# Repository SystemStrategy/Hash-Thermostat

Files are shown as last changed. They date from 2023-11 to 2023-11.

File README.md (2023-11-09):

# Hash-Thermostat

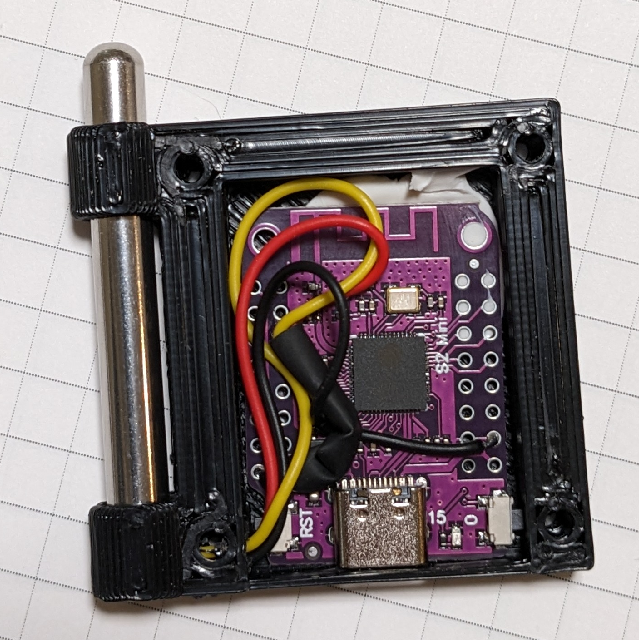
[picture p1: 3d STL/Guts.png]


Braiins OS Hash Thermostat to regulate indoor temperature using the miner API to go between pause and reusme

Tested on an S9 and works, but if you have a newer more supported miner by braiins, there exists the capability to ramp power output up and down. Please put in an issue if you want to dev/test this with me.

Parts used:
ESP32S2 Mini - https://www.wemos.cc/en/latest/s2/s2_mini.html

Temperature Probes Options:
DS18B20
AHT21

Wiring for AHT21
GPIO 21 (SDA)
GPIO 22 (SCL)

Wiring for DS18B20
GPIO 04 with 4.7k pullup resistor to Vcc(3.3v)

Hash Thermostat Quick Start Guide:

Step 1:
	Connect to the WIFI access point “AP_Thermostat” the password is “StackSats!”
	Note: WIFI access point deactivates when rebooted and device connects to network

Step 2:
	Open your web browser and navigate to http://194.168.4.1 or http://thermostat.local/   		
	-Login prompt the username and password are “admin” click “Sign In”

Step 3:
	Enter the desired thermostat behavior using the sliders and click “Apply Settings”

Step 4:
	Navigate to "Configuration" then “Network Parameters”
	
	-Enter Wifi SSID and Password and click “submit” 
	 	If network has connected you should see the Status change to “Connected” otherwise double check the credentials

	-Enter the Miner Static IP and click “submit” 
		If the miner is connected the Status changes to “Hashing” or “Off” depending on the state
	
	-Click the Time Zone dropdown to select your Time Zone and click “submit” 

	When all looks good, click “Main Page”

Step 5: 
	Change the Login Password

Step 6: 
	If you have an MQTT broker you want to send data to click “MQTT Parameters”

Step 7:
	Click the “Reboot” Button
	You should be able to find the device by typing “http://thermostat.local/” in the browser

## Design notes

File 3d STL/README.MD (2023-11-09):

Assembly Notes:

Cut DS18B20 wires to 4 inches from the base of the metal shell
Remove the heat shrink tube
carefully remove the rubber wire jacket

3d print cleanup
use 15/64 inch bit to clear DS18B20 holes
then use 1/4 inch bit to clear the first hole

insert the DS18B20 though the first hole and into the case
then push the temperature sensor in

Solder up the connections for the ESP32S2 Mini

Close using M3*6 screws

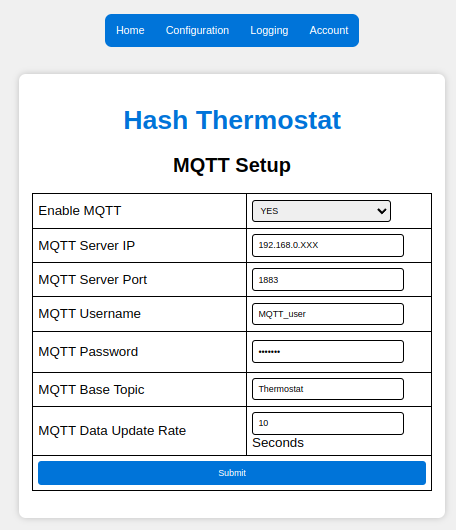
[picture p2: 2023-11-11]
Webpage_Images/MQTT.png

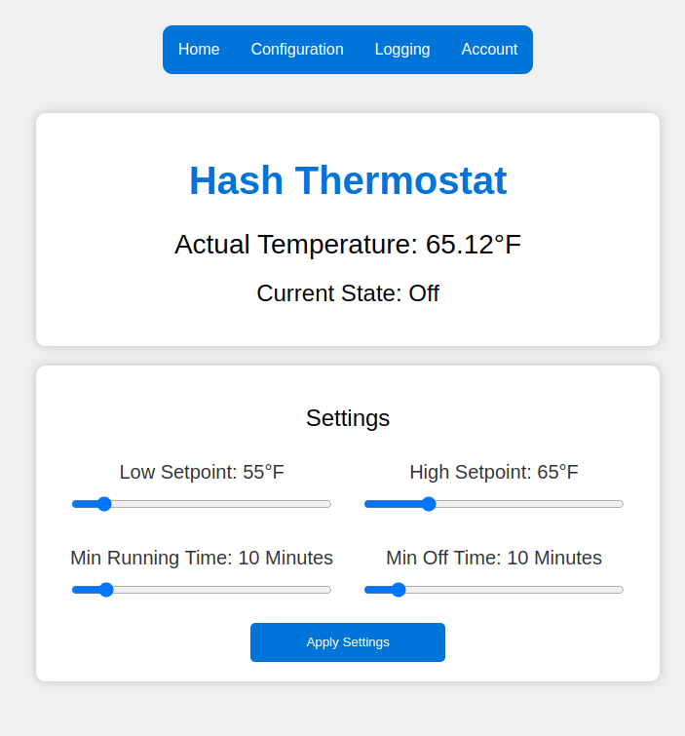
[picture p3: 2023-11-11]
Webpage_Images/Settings.png

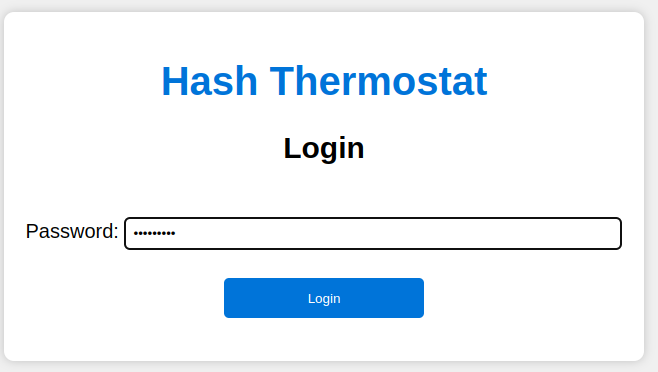
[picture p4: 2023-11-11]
Webpage_Images/Login.png

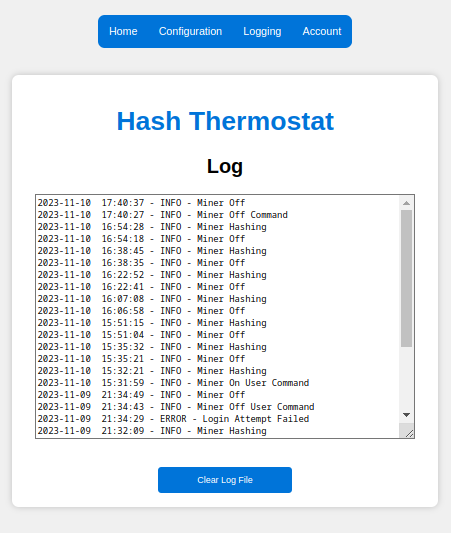
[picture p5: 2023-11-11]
Webpage_Images/Log.png

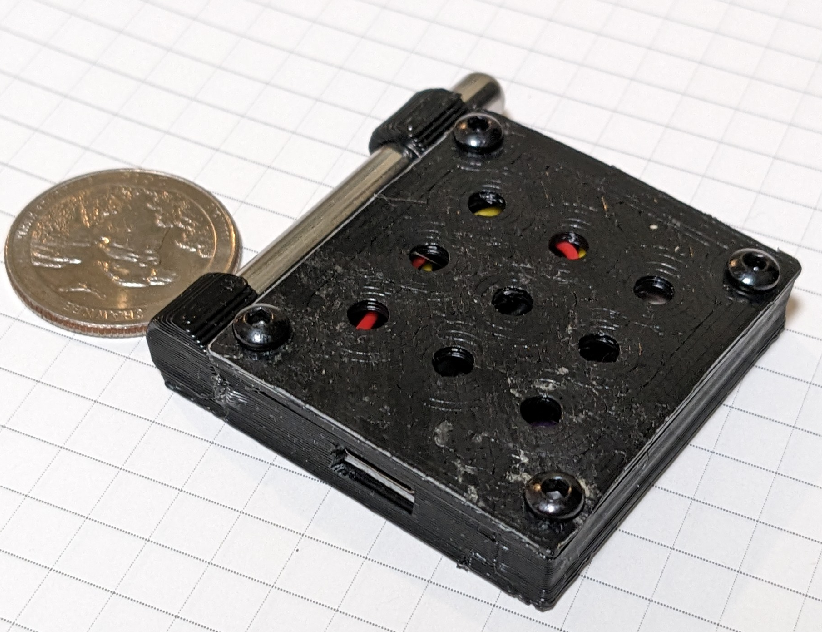
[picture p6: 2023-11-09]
3d STL/Orthogonal.png

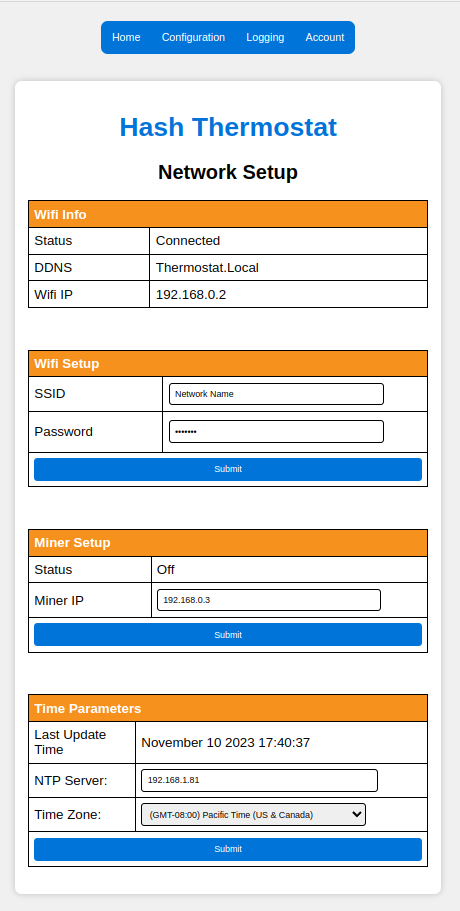
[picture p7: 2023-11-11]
Webpage_Images/Network.png

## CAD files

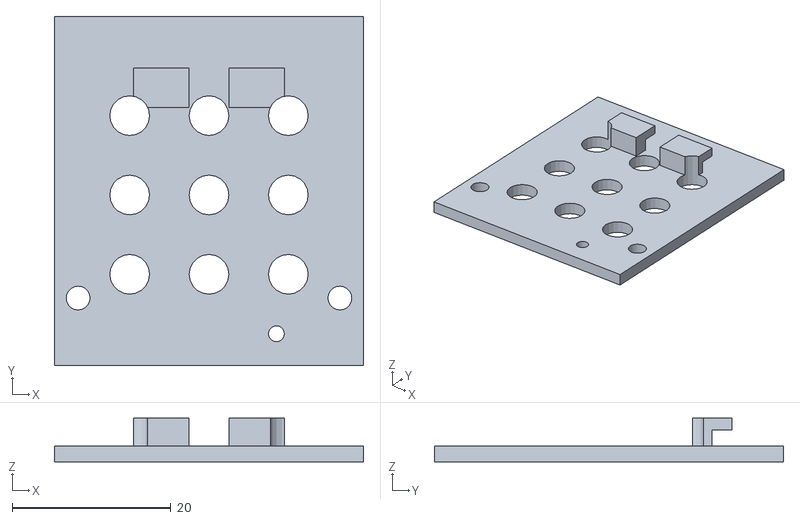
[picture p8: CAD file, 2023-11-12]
3d STL/Thermostat V3.2_cover.stl
39.0 x 44.0 x 5.50

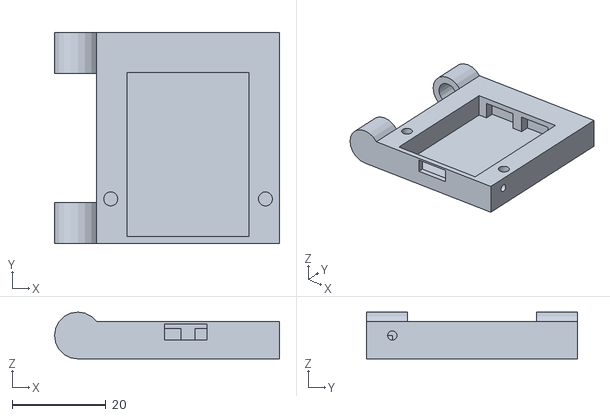
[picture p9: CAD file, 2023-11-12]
3d STL/Thermostat V3.2.stl
48.0 x 45.0 x 10.0

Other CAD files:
3d STL/Thermostat V3.1_cover.stl
3d STL/Thermostat V3.stl

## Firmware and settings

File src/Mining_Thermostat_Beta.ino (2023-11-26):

char Version[12] = "Dev V1.07";

int Boot_Button = 0;
int LED_Pin = 15;
bool Miner_Offline = false;
int Miner_Status;  //0=Off,1=ON
int Power;
String Miner_IP;
String Miner_Status_str = "Offline";
int Temp_Low = 71;
int Temp_High = 80;
int Min_Off_Time = 10;
int Min_Run_Time = 10;
String Login_Password = "admin";

String Wifi_SSID;
String Wifi_Password;

bool mqtt_enabled = false;
String mqtt_server;
int mqtt_server_port = 1883;
String mqtt_username;
String mqtt_password;
String mqtt_base_topic = "Hash_Thermostat";
int mqtt_update_rate = 10;  //seconds



bool Poll_Miner;
bool last_Miner_Status;
bool Miner_Offline_Now;
bool last_Miner_Offline;
bool last_MQTT_Connected;

bool last_Temp_Sensor_Error;

bool Wifi_Station_Mode = false;

//NTP Variables
String NTP_Time;
struct tm timeinfo;
String NTP_Server = "pool.ntp.org";
int UTC_Offset;
int EN_DST;
int TimeID = 5;

unsigned long Uptime = 0;
long Miner_Poll = 1;
unsigned long Wifi_Retry_Timer = 0;
unsigned long lastUptime = 0;
unsigned long lastMsg = 0;
unsigned long last_Temp_Measure = 0;
unsigned long lastRun = 0;
unsigned long lastOff = 0;
unsigned long lastMQTT = 0;
unsigned long MQTT_Startup_Delay = 0;
unsigned long Time_Validation = 0;
unsigned long Miner_Offline_Timer = 0;
unsigned long now;

char Stored_Version[12];
char mqtt_server_Val[20];
char mqtt_username_Val[30];
char mqtt_password_Val[30];


#include "Temperature_Sensor.h";
TemperatureSensor tempSensor;

//Wifi Stuff
#include <WiFi.h>
#include <WebServer.h>
#include <ESPmDNS.h>
#include <Update.h>
#include "time.h"
#include "ntp_handler.h";
WebServer server(80);  //Server on port 80
#include "file_handler.h"
#include "API.h"

#include "MQTT_Handler.h";
MQTTManager mqttManager;

String Current_Webpage;
#include "webpages.h"
#include "webpage_handler.h"




void setup_wifi() {
  char SSID_Val[20];
  char Pass_Val[30];
  Wifi_SSID.toCharArray(SSID_Val, Wifi_SSID.length() + 1);
  Wifi_Password.toCharArray(Pass_Val, Wifi_Password.length() + 1);

  WiFi.mode(WIFI_STA);
  WiFi.begin(SSID_Val, Pass_Val);  //Connect to your WiFi router
  int count = 0;
  int attempts = 1;

  Serial.println("");
  Serial.print("Attempt : ");
  Serial.println(attempts);
  while (WiFi.status() != WL_CONNECTED) {
    delay(100);
    digitalWrite(LED_Pin, LOW);
    delay(100);
    digitalWrite(LED_Pin, HIGH);
    count++;
    Serial.print(".");
    if (count >= 50) {  //after 3 seconds of no connection give up
      attempts++;
      if (attempts >= 3) {
        break;
      }
      Serial.println("");
      Serial.print("Attempt : ");
      Serial.println(attempts);
      WiFi.disconnect();
      while (WiFi.status() == WL_CONNECTED) {
        delay(100);
        count++;
        if (count >= 30) break;
      }
      WiFi.begin(SSID_Val, Pass_Val);  //Connect to your WiFi router
      count = 0;
    }
  }
}

void reconnect_wifi() {
  Serial.println("Wifi Reconnecting");
  WiFi.disconnect();
  yield();
  delay(100);
  setup_wifi();
}




void setup() {
  Serial.begin(115200);
  pinMode(Boot_Button, INPUT);
  pinMode(Boot_Button, INPUT_PULLUP);
  pinMode(LED_Pin, OUTPUT);
  delay(1000);
  if (!SPIFFS.begin(FORMAT_LITTLEFS_IF_FAILED)) {
    Serial.println("LITTLEFS Mount Failed");
    File_Avaliable = false;
    return;
  } else File_Avaliable = true;

  Read_Parameters_File(SPIFFS, "/Parameters.txt");

  mqtt_server.toCharArray(mqtt_server_Val, mqtt_server.length() + 1);
  mqttManager.setServer(mqtt_server_Val, mqtt_server_port);


  mqtt_username.toCharArray(mqtt_username_Val, mqtt_username.length() + 1);
  mqtt_password.toCharArray(mqtt_password_Val, mqtt_password.length() + 1);
  mqttManager.setcreds(mqtt_username_Val, mqtt_username_Val, mqtt_password_Val);


  if (!Wifi_Station_Mode) {
    WiFi.mode(WIFI_AP);
    WiFi.softAP("AP_Thermostat", "StackSats!");  //Configuration Access Point
  } else setup_wifi();

  if (WiFi.status() == WL_CONNECTED) {
    Serial.println("");
    Set_NTP_Server();
    printLocalTime();
    delay(1000);
  }

  MDNS.begin("thermostat");
  Start_Web_Services();
  Create_Cookie_Tolken();
  tempSensor.initialize();


  now = millis();
  lastMsg = now - 5000;

  lastLoginTime = now;
  lastUptime = now;
  lastRun = now;
  lastOff = now;
  lastMQTT = now;
  MQTT_Startup_Delay = now;
  Time_Validation = now;
  Miner_Offline_Timer = now;

  if (strcmp(Stored_Version, Version) != 0) {
    if (strcmp(Stored_Version, "") != 0) Append_Log_File("INFO - Firmware Updated");
    Save_Parameters_File();
  }
  char buf[30];
  sprintf(buf, "INFO - Device Boot ");
  strcat(buf, Version);
  Append_Log_File(buf);




  Serial.println(WiFi.localIP());
}


void loop() {

  digitalWrite(LED_Pin, HIGH);
  if (digitalRead(Boot_Button) == false) {  //Enter into AP Config
    deleteFile(SPIFFS, "/Log.txt");
    deleteFile(SPIFFS, "/Parameters.txt");
    digitalWrite(LED_Pin, LOW);
    delay(2000);
    ESP.restart();
  }

  now = millis();
  server.handleClient();  //Handle client requests
  yield();
  delay(100);

  if (now - lastUptime > 1000) {
    lastUptime = now;
    Uptime++;
  }


  //Temperature Sensor Updates
  if (now - last_Temp_Measure > 10000) {
    last_Temp_Measure = now;

    tempSensor.measureTemperature();


    if ((last_Temp_Sensor_Error != tempSensor.hasError()) && tempSensor.hasError()) Append_Log_File("ERROR - Temperature Sensor Offline");
    else if ((last_Temp_Sensor_Error != tempSensor.hasError()) && !tempSensor.hasError()) Append_Log_File("INFO - Temperature Sensor Online");
    last_Temp_Sensor_Error = tempSensor.hasError();
  }

  if (Wifi_Station_Mode) {
    if (WiFi.status() != WL_CONNECTED) {
      reconnect_wifi();
      Append_Log_File("INFO - Wifi Reconnect");
    }

    if (now - lastMsg > (10000 * Miner_Poll)) {
      lastMsg = now;
      if (WiFi.status() == WL_CONNECTED) {

        if (Get_Miner_Status()) {
          Miner_Offline_Now = true;
        } else {
          Miner_Offline_Now = false;
          Miner_Offline_Timer = now;
        }


        if ((last_Miner_Offline != Miner_Offline) && Miner_Offline) Append_Log_File("ERROR - Miner Offline");
        else if ((last_Miner_Offline != Miner_Offline) && !Miner_Offline) Append_Log_File("INFO - Miner Online");
        last_Miner_Offline = Miner_Offline;

        if ((last_Miner_Status != Miner_Status) && !Miner_Status) Append_Log_File("INFO - Miner Off");
        else if ((last_Miner_Status != Miner_Status) && Miner_Status) Append_Log_File("INFO - Miner Hashing");
        last_Miner_Status = Miner_Status;



        if (now - Miner_Offline_Timer > 20000) {
          Miner_Offline = true;
          Miner_Poll = 3;
        } else {
          Miner_Poll = 1;
          Miner_Offline = false;
          if (Miner_Status == 0) lastRun = now;
          else if (Miner_Status == 1) lastOff = now;
        }

        if (!tempSensor.hasError()) {
          float Actual_Temp = tempSensor.getTemperature();
          if ((Actual_Temp < Temp_High) && (Actual_Temp > Temp_Low)) Time_Validation = now;

          if (!Miner_Offline_Now) {
            Serial.println("Command Start");
            if (now - Time_Validation > (5 * 60000)) {  //5 minute delay before turning on or off to prevent miss-reads or false conditions
              if (now - lastRun > (Min_Run_Time * 60000)) {
                //Allowed to turn Off
                if (Actual_Temp > Temp_High) {
                  if (Miner_Status != 0) {
                    delay(100);
                    Append_Log_File("INFO - Miner Off Command");
                    Miner_Set_Off();
                    yield();
                  }
                }
              }
              yield();

              if (now - lastOff > (Min_Off_Time * 60000)) {
                //Allowed to turn On
                if (Actual_Temp < Temp_Low) {
                  if (Miner_Status != 1) {
                    delay(100);
                    Append_Log_File("INFO - Miner On Command");
                    Miner_Set_On();
                    yield();
                  }
                }
              }
            }
          } else {  // If the temp sensor goes offline for a minute turn the miner off
            if (tempSensor.getlastupdate() > 60000) {
              if (Miner_Status != 0) {
                Append_Log_File("ERROR - Temperature Sensor Failed");
                delay(100);
                Append_Log_File("INFO - Shutting Miner Down");
                Miner_Set_Off();
                yield();
              }
            }
          }
        }
      }
    }
    if (mqtt_enabled) {
      if (!mqttManager.checkConnection()) {
        mqttManager.setServer(mqtt_server_Val, mqtt_server_port);
        mqttManager.setcreds(mqtt_username_Val, mqtt_username_Val, mqtt_password_Val);
      }
      else if (now - lastMQTT > (mqtt_update_rate * 1000)) {
        lastMQTT = now;


        char mqtt_base_topic_Val[30];
        mqtt_base_topic.toCharArray(mqtt_base_topic_Val, mqtt_base_topic.length() + 1);

        mqttManager.publishTempSensorData(mqtt_base_topic_Val, tempSensor.getTemperature(), !tempSensor.hasError());
        mqttManager.publishMinerData(mqtt_base_topic_Val, Miner_Offline, Miner_Status, Power);
        mqttManager.publishParameterData(mqtt_base_topic_Val, Uptime, Temp_Low, Temp_High, Min_Off_Time, Min_Run_Time);
      }
    }
    yield();
  }
}

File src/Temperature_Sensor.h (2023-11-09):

#include <OneWire.h>
#include <DallasTemperature.h>
#include <Wire.h>
#include <Adafruit_AHTX0.h>

// Define your sensor type based on a runtime condition
#define AHT_SENSOR false
#define DS18B20_SENSOR true
#define ONE_WIRE_BUS 4

class TemperatureSensor {
public:
  TemperatureSensor()
    : Temp_Sensor_Error(false), last_Temp_Measure(0) {
    if (AHT_SENSOR) {
      aht = new Adafruit_AHTX0();
      ds18b20 = nullptr;  // DS18B20 is not used
    } else if (DS18B20_SENSOR) {
      oneWire = new OneWire(ONE_WIRE_BUS);
      ds18b20 = new DallasTemperature(oneWire);
      ds18b20->begin();
      deviceCount = ds18b20->getDeviceCount();
      deviceAddress = new DeviceAddress[deviceCount];
      ds18b20->requestTemperatures();
      ds18b20->getAddress(deviceAddress[0], 0);  // Get the unique address of the first DS18B20
      ds18b20->setResolution(deviceAddress[0], 11);
    }
  }

  bool initialize() {
    if (AHT_SENSOR) {
      if (aht->begin()) {
        return aht->getStatus() != 255;
      }
    } else if (DS18B20_SENSOR) {
      ds18b20->requestTemperatures();
      if (ds18b20->getTempC(deviceAddress[0]) == -127) {
        Temp_Sensor_Error = true;
      } else {
        last_Temp_Measure = millis();
        Temp_Sensor_Error = false;
        Actual_Temp = ((ds18b20->getTempC(deviceAddress[0]) * 9 / 5) + 32) - 3.1;  // convert from C to F and offset by 3.1 degrees
      }
    }
    return false;
  }

  bool hasError() const {
    return Temp_Sensor_Error;
  }

  void measureTemperature() {
    if (AHT_SENSOR) {
      sensors_event_t humidity, temp;
      aht->getEvent(&humidity, &temp);

      if (aht->getStatus() == 255) {
        Temp_Sensor_Error = true;
      } else {
        last_Temp_Measure = millis();
        Temp_Sensor_Error = false;
        Actual_Temp = ((temp.temperature * 9 / 5) + 32);  // convert from C to F
      }
    } else if (DS18B20_SENSOR) {
      ds18b20->requestTemperatures();
      float tempC = ds18b20->getTempC(deviceAddress[0]);
      if ((tempC == -127) || isnan(tempC)) {
        Temp_Sensor_Error = true;
        ds18b20->getAddress(deviceAddress[0], 0);  // Get the unique address of the first DS18B20
        ds18b20->setResolution(deviceAddress[0], 11);
      } else {
        last_Temp_Measure = millis();
        Temp_Sensor_Error = false;
        Actual_Temp = ((tempC * 9 / 5) + 32) - 3.1;  // convert from C to F
      }
    }
  }

  float getTemperature() const {
    return Actual_Temp;
  }

  unsigned long getlastupdate() const {
    return millis() - last_Temp_Measure;
  }

private:
  float Actual_Temp;
  bool Temp_Sensor_Error;
  unsigned long last_Temp_Measure;
  Adafruit_AHTX0 *aht;
  OneWire *oneWire;
  DallasTemperature *ds18b20;
  DeviceAddress *deviceAddress;
  int deviceCount;
};

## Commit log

2023-11-03 Update Mining_Thermostat_Beta.ino
    MQTT Online fix
    [Mining_Thermostat_Beta.ino]
2023-11-06 Update webpage_handler.h
    Reset lastLoginTime to millis()
2023-11-09 Update Temperature_Sensor.h
    Enable DS18B20 Sensor
2023-11-12 Update Mining_Thermostat_Beta.ino
    Changed Minor Rev to 1.06
    Added LED Indicator light and reset button
2023-11-12 Update webpage_handler.h
    Added LED Light Blink when connecting to wifi
2023-11-12 Add files via upload
    Added LED View Port and pin hole button to reset
    [Thermostat V3.2.stl, Thermostat V3.2_cover.stl]
2023-11-12 Add files via upload
    V1.06 Binary for ESP32S2 Mini
2023-11-26 Update Mining_Thermostat_Beta.ino
    V1.07
    MQTT Bug fixes:
    MQTT update rate was not changing the published data
    [Mining_Thermostat_Beta.ino]
